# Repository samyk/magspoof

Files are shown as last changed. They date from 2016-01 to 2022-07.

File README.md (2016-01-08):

# [MagSpoof](http://samy.pl/magspoof/) - credit card/magstripe spoofer
* Allows you to store all of your credit cards and magstripes in one device
* Works on traditional magstripe readers **wirelessly** (no NFC/RFID required)
* Can **disable** Chip-and-PIN (code not included)
* Correctly **predicts** Amex credit card numbers + expirations from previous card number (code not included)
* Supports all three magnetic stripe tracks, and even supports Track 1+2 simultaneously
* Easy to build using Arduino or other common parts

**[MagSpoof](http://samy.pl/magspoof)** is a device that can spoof/emulate any magnetic stripe or credit card. It can work "wirelessly", even on **standard magstripe/credit card readers**, by generating a strong electromagnetic field that emulates a traditional magnetic stripe card.

**Note:** MagSpoof does **not** enable you to use credit cards that you are not legally authorized to use. The Chip-and-PIN and Amex information is **not** implemented and using MagSpoof requires you to have/own the magstripes that you wish to emulate. Simply having a credit card number and expiration is not enough to perform transactions. MagSpoof **does** allow you to perform research in other areas of magstripes, microcontrollers, and electromagnetism, as well as learn about and create your own devices similar to other existing, commercial technologies such as <a href="http://www.samsung.com/us/support/answer/ANS00043865/997410383/">Samsung MST</a> and <a href="https://onlycoin.com/">Coin</a>.</p>

Visualizing magstripe data (http://samy.pl/magspoof/meter-small2.gif)

MagSpoof can be used as a traditional credit card and simply store all of your credit cards (and with modification, can technically disable chip requirements) in various impressive and exciting form factors, or can be used for security research in any area that would traditionally require a magstripe, such as readers for credit cards, drivers licenses, hotel room keys, automated parking lot tickets, etc.

**Live demonstration** and more details available in the video:
<a href="https://www.youtube.com/watch?v=UHSFf0Lz1qc" target="_blank">MagSpoof</a>

**Point of Contact:** [@SamyKamkar](https://twitter.com/samykamkar) // <code@samy.pl> // <http://samy.pl>

**Released:** November 24, 2015

**Source code / schematic:** [https://github.com/samyk/magspoof](https://github.com/samyk/magspoof)

-----

# How magnetic stripes work

Visualizing magstripe data (http://samy.pl/magspoof/iron-oxide-short-low.gif)

Magnetic stripes (magstripes) are in fact magnetic. What's so cool about magstripes is that while the magnetic strips inside are weak, they're still strong enough to attract small ferrous particles and wide enough that we can **fully extract all data from a magstripe or credit card with the naked eye**. 

In the video, I actually dip my credit card into a bag of iron oxide. The magnetic elements in the magstripe attract the iron oxide and after pulling it out, you can actually see each bit in the tracks. [Financial cards](https://en.wikipedia.org/wiki/Magnetic_stripe_card#Financial_cards) with magnetic strips can have up to three tracks, however credit cards only have two tracks (Tracks 1 and 2). Track 2 stores fewer bits than Track 1, so it has a lower linear density (bits per inch).  This makes Track 2 much easier to see. Let's take a look:

Credit card magnetic stripe (http://samy.pl/magspoof/mag1.png)

Front of card:

Credit card magnetic stripe (http://samy.pl/magspoof/cc-front.jpg)

As you can see on my card, I've written out the bits above the strips. Two solid stripes is a 1 and a stripe followed by a space is a 0. First, let's flip the card 180 degrees (looking at it upside down), and read it as least significant bit first. We ignore all the initial 0's until the very first 1.

Track 2 is 5 bits per character, least significant bit first, and the 5th bit is an odd parity bit. By taking each 5 bits and reading the first 4 bits, we can now begin extracting the credit card number (and other data, such as expiration date, discretionary data, CVV/CVC/CSC/CID/CAV depending on card type).

Note that the CVV is different than the CVV2. The CVV is stored on the magstripe, while the CVV2 is printed on a card. (CVV is specific to Visa, and each issuer has their own name such as CSC, CVC, etc.)

Credit card magnetic stripe (http://samy.pl/magspoof/cciron.jpg)

------

# How MagSpoof Works

MagSpoof emulates a magnetic stripe by quickly changing the polarization of an electromagnet, producing a magnetic field similar to that of a normal magnetic stripe as if it's being swiped. What's incredible is that the magstripe reader requires no form of wireless receiver, NFC, or RFID -- MagSpoof works wirelessly, even with **standard magstripe readers.** The stronger the electromagnet, the further away you can use it (a few inches in its current iteration).

MagSpoof also uses inexpensive, off the shelf parts (described in the Hardware section), and can be built with almost nothing more than an Arduino, wire and a battery! I use a motor driver to provide a reasonable amount of power.

Normally electromagnets have an iron core, however we lose the core for the sake of space and portability. Also, while the iron core does make the electromagnet more efficient, we still produce more than enough power to work.

**MagSpoof improves on new cards such as Coin.** I'm a customer of Coin, and while I love their app and the card, the card actually works a very small percentage of the time. After looking over Coin's FCC docs, I noticed they use two coils to produce a (very small) electromagnetic field, however it's severely deficient and the card works less than 50% of the time for me, sadly.

I found that by emulating a card with MagSpoof, if I send Track 1 one way, and then send Track 2 reversed, every card reader will assume I simply swiped a card back and forth, use the data from both tracks and my strong electromagnet, and properly read all of the data. This is extremely effective, uses only a single coil, and works for both tracks simultaneously. This also allows MagSpoof to work on Track 3.

Additionally, if you're using a Chip card with Coin, you **still** need to bring your actual credit card to dip, however because MagSpoof can disable Chip-and-PIN (see below), it does **not** require you to bring your card with you.

I've removed the Chip-and-PIN disabling functionality from MagSpoof.

-----

# Security Issues

One of the primary issues I've found is that some of the new forms of security (well, new in the US) are set in the "service code" portion of the magstripe, most specifically **Chip-and-PIN.**

The service code within a credit card magstripe defines several attributes of the card, including whether the card can dispense cash, where it can work (nationally, internationally), and most interestingly, whether the card has a built in IC (Chip) and if it has a pin (Chip-and-PIN / EMV).

If your card has a chip inside and you go to a retailer that supports Chip but swipe just your magstripe, the point of sale (PoS) system will ask you to dip your card/chip for additional security if it supports it.

**However, the bits stating the card has Chip-and-PIN can be turned off from the magstripe.** This means if you take a card to a retailer that would normally request you to dip, you can actually get away with not dipping your chip at all while performing a successful transaction, **evading the security measures altogether**.

Credit Card Service Codes (http://samy.pl/magspoof/servicecodes.jpg)

------

# American Express Card Number Prediction

What initially led me to investigate magnetic stripes was my Amex card. After losing a card and Amex quickly sending me a replacement, I noticed many of the digits were similar. I pulled up the numbers to several other Amex cards I had, and then compared against more than 20 other Amex cards and replacements and found **a global pattern that allows me to accurately predict American Express card numbers by knowing a full card number, even if already reported lost or stolen.**

This means if I were to obtain your Amex card and you called it in as lost or stolen, the moment you get a new card, I know your new credit card number.

I also know the new expiration date as the expiration date is fixed based on when the new card was requested, and you can determine if the new card has been requested by performing an auth on the existing card.

The CID (aka CVV2 on Visa) printed on the card is protected by a secret 3DES key that encrypts the PAN (Primary Account Number, aka credit card number), service code (see above), and expiration. The service code can be easily determined as most cards will contain the same service code.

I also determined that the CSC (essentially behaves like a CID or CVV2 on the magstripe) for a lost or stolen card **continues to work** for a newer, predicted card. An attacker would be able to use a stolen card's CSC with the predicted card number and expiration to make actual purchases.

To actually perform the transaction without arousing suspicion, an attacker would be able to use a magstripe writer (e.g., the well known MSR605), or a device like MagSpoof, to "load" the newly devised card information onto a card like Coin. Coin itself does not actually verify the CID (CVV2), thus allowing an attacker to load data, and then use the Coin card in person without knowing the CID and exploiting these various issues, as well as disabling Chip-and-PIN.

I notified American Express of the issue and I will not be releasing their algorithm.

-----

# Hardware

MagSpoof (http://samy.pl/magspoof/magspoof.jpg)

### [Atmel ATtiny85](http://amzn.to/1S3ha9s) (microcontroller)
An Atmel ATtiny85 is the microcontroller to drive the entire system. It stores all of the magnetic stripe / credit card data. In a thinner, credit-card sized (0.8mm thick!) version, I use an [ATtiny10].

### [L293D H-Bridge](http://amzn.to/1S3h9Ck) (motor driver)
I use an L293D H-bridge to drive the electromagnet. The L293D is a motor driver, but motors are actually driven by the electromagnet(s) and magnets inside of them. Any standard driver should work here. Technically the L293D doesn't work down at 3.7V (voltage of the LiPo battery), but it works surprisingly well. In the credit-card size version, I suggest using a the TI DRV8835 or [TI DRV8833](http://amzn.to/1lu0bTd).

### [24AWG Magnet Wire](http://amzn.to/1lu0ihK) (coil)
I use somewhere around ~24AWG magnet wire to act as the coil to produce the electromagnetic field. This piece of wire incredibly produces an electromagnetic field that makes the card reader believe a card is being swiped. Incredible. By rapidly controlling the polarization of this field, the magstripe reader believes the flipped bits of a real card are being swiped through the reader.

### [100mAh 3.7V LiPo battery](http://amzn.to/1S3h69E) (the powah)
A small 100mAh 3.7V lipo battery powers our contraption. For the credit card size version (not shown here), I use a battery from [PowerStream](http://www.powerstream.com/thin-lithium-ion.htm).

#### [100µF Capacitor](http://amzn.to/1MAONOc)
Keep enough energy in this capacitor to provide the electromagnet with power when we need it, otherwise it will pull too much current and reset the microcontroller. This is the capacitor kit I use as it has all the standard values I'd need.

#### [LED](http://amzn.to/1Hl3y8Z)
To signal to us when we transmit information. I use this LED kit as it has a nice variety of LEDs.

#### [100Ω Resistor](http://amzn.to/1IeCMtP)
Don't burn out the LED.

#### [Momentary Switch](http://amzn.to/1Hl3R3T)
Initiate the electromagnet.

#### [Mini-Protoboard](http://amzn.to/1Hl3VQV)
For soldering everything together.

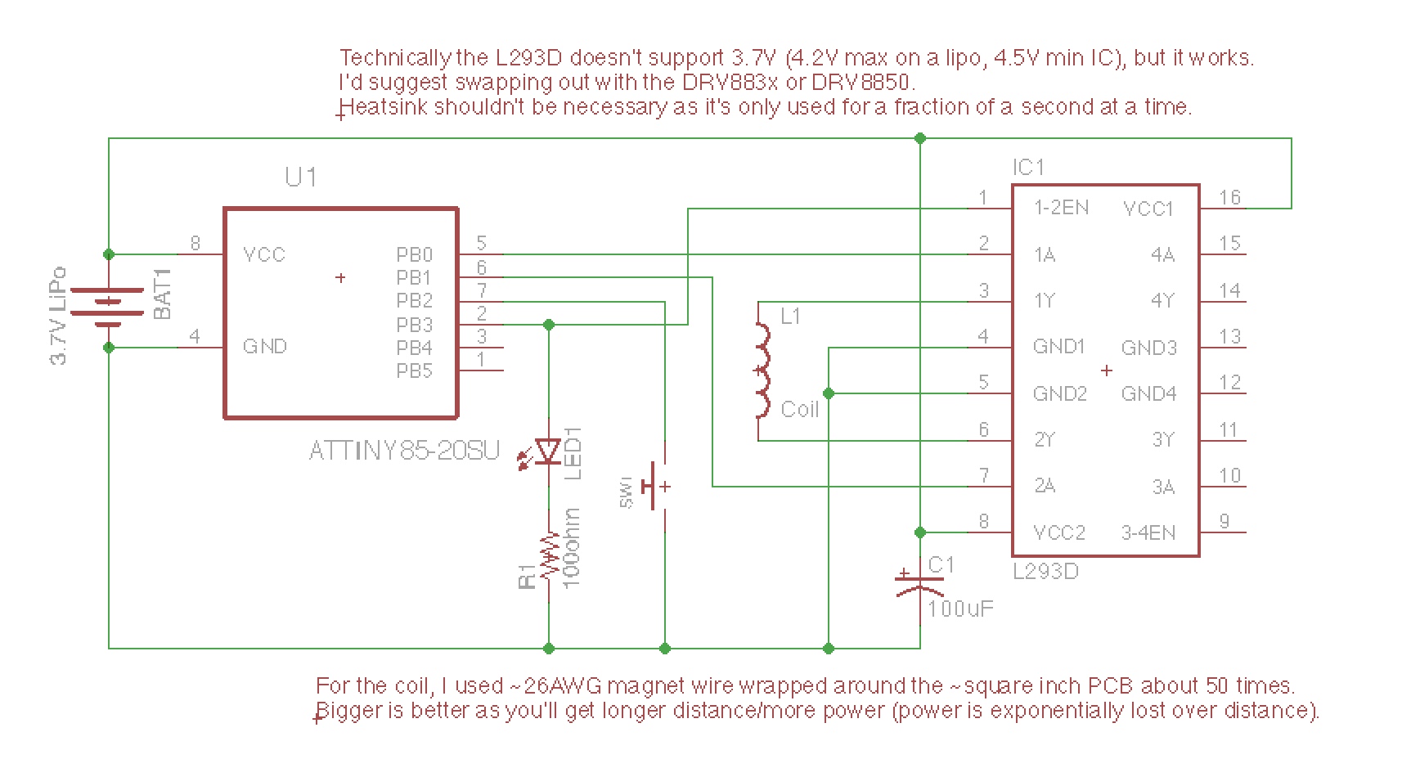
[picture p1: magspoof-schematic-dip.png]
MagSpoof Schematic (DIP version)


-----

# Firmware

### MagSpoof
MagSpoof's source code and schematic can be obtained in entirety from my github: <https://github.com/samyk/magspoof>

MagSpoof is compatible with the Arduino framework and can work on traditional Arduinos as well as ATtiny chips.

-----
# Resources

You can learn about magnetic stripes and credit cards from a few places, including:

* [My video on MagSpoof](https://www.youtube.com/watch?v=UHSFf0Lz1qc)
* [ISO/IEC 7810](https://en.wikipedia.org/wiki/ISO/IEC_7810)
* [ISO/IEC 7811](https://en.wikipedia.org/wiki/ISO/IEC_7811)
* [ISO/IEC 7812](https://en.wikipedia.org/wiki/ISO/IEC_7812)
* [ISO/IEC 7813](https://en.wikipedia.org/wiki/ISO/IEC_7813)
* [ISO 8583](https://en.wikipedia.org/wiki/ISO_8583)
* [ISO/IEC 4909](https://en.wikipedia.org/wiki/ISO/IEC_4909)
* [MagTek Magnetic Stripe Standards](http://www.magtek.com/documentation/public/99800004-1.08.pdf) (pdf)
* [Magnetic Stripe Card on Wikipedia](https://en.wikipedia.org/wiki/Magnetic_stripe_card)
* [Amex's Web Services Plural Interface](http://secure.cmax.americanexpress.com/Internet/MSWS/English/PIP-XML_Oct2010.pdf)

-----

# Contact

**Point of Contact:** [@SamyKamkar](https://twitter.com/samykamkar)

You can see more of my projects at <http://samy.pl> or contact me at <code@samy.pl>.

------

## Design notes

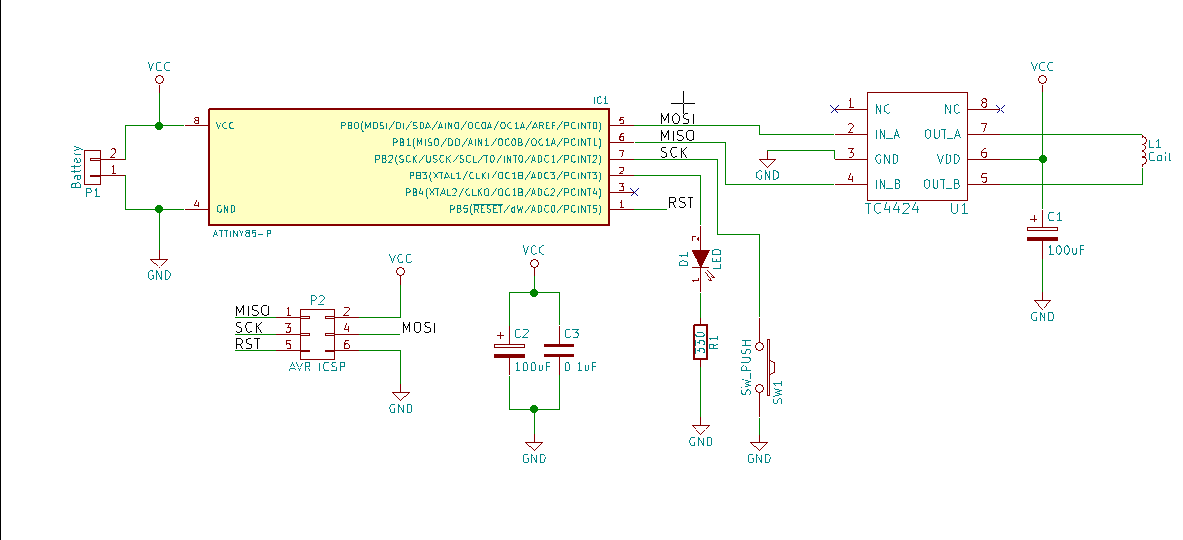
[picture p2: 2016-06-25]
KiCad-PCB/Schematic.png

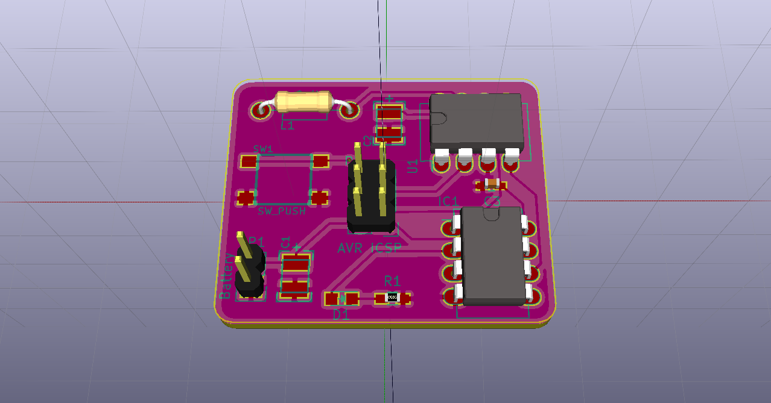
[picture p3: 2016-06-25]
KiCad-PCB/RenderBoard.png

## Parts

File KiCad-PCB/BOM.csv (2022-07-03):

Reference, Value, Footprint, Datasheet, Manufacturer, Temperature, Feed, Description, Temperatura, Alimentacion, Descripción
IC1,ATTINY85-P,Housings_DIP:DIP-8_W7.62mm_LongPads,http://www.farnell.com/datasheets/1744708.pdf,ATMEL,+85*C/-40*C,5v,Low Power High Performance ATMEL ATTINY85-20PU Microcontroller 20MHZ 8 Bits 8 KB 512 Byte 8 Pin Dip Through hole, +85*C/-40*C,5V, Baja Potencia Alto Rendimiento ATtiny Microcontrolador 20 MHz 8 KB 512 Byte 8 pines zambullida través agujero
D1,LED,LEDs:LED-0805,,Maxim,+85/-40,5v,Led red 0805
L1,Coil,Resistors_ThroughHole:Resistor_Horizontal_RM10mm,
R1,330,Resistors_SMD:R_0603_HandSoldering,,,+85/-40,5v,Resistor 330ohms
C1,100uF,theinventorhouse:1411(3528m)-B%2CM%2CH%2CT-TANTALUM,http://www.farnell.com/datasheets/1923743.pdf,Kemet,+85/-40,6.3v,KEMET 	T520T107M006ATE070  CAP, TANT, POLYMER, 100UF, 6.3V, 1411
SW1,SW_PUSH,open-project:SW_PUSH_SMD,
P2,AVR ICSP,Pin_Headers:Pin_Header_Straight_2x03,,Maxim,+85/-40,5v,
P1,Battery,Pin_Headers:Pin_Header_Straight_1x02,
C3,0.1uF,Capacitors_SMD:C_0603_HandSoldering,http://www.farnell.com/datasheets/2009679.pdf,WALSIN,+85/-40,50v,WALSIN 	0603F104Z500CT  CAP, MLCC, Y5V, 0.1UF, 50V, 0603, REEL
U1,TC4424,Housings_DIP:DIP-8_W7.62mm_LongPads,http://www.farnell.com/datasheets/95980.pdf,Microchip,+85/-40,2.7-5v,MICROCHIP 	TC4424CPA  MOSFET Driver Lado Bajo, Alimentación:4.5-18V, Salida Pico:3A, Salida:3.5 Ohm, DIP-
C2,100uF,theinventorhouse:1411(3528m)-B%2CM%2CH%2CT-TANTALUM,http://www.farnell.com/datasheets/1923743.pdf,Kemet,+85/-40,6.3v,KEMET 	T520T107M006ATE070  CAP, TANT, POLYMER, 100UF, 6.3V, 1411

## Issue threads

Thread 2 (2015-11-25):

Having a license?

ifraixedes, 2015-11-25:
Hi @samyk

Nice job!

I would appreciate if you can define a license for all of this information; whatever you want, but it would be useful to know which one that leaving it under people and laws interpretations.

Thanks so much to release this information.

madmod, 2015-11-25:
+1 This is an awesome project and I would like to know if I can make my own version of this for friends. Also I'm investigating an iPhone case version powered by the camera flash led.

samyk, 2015-11-27:
I'll start reading up on licenses.

Great idea on one powered by the camera flash LED, that would be very cool. Please share any info if you do create that!

ifraixedes, 2015-11-27:
@samyk thanks for your time to think about it

Luabee, 2016-10-07:
Have you considered a license for this yet? I'm interested in building upon this project and selling it.

samyk, 2016-10-08:
I've created and added a license, and will likely use this for future projects and all previous projects which are not yet licensed.

License added to git and provided at https://github.com/samyk/bpl/

0ki, 2017-09-06:
Is that a joke?

Closed 2016-10-08.

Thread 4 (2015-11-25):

Pictures of credit card sized version

madmod, 2015-11-25:
Please consider adding this as it sounds really awesome and I'm sure everyone would love to see it!

0ki, 2015-11-26:
Do you mean the coin? Internet is full of pictures. Also, here's a promo video: https://www.youtube.com/watch?v=gJBZMUuhUrw

madmod, 2015-11-26:
No I already own a coin. It's pretty cool although I haven't gotten the NFC feature to work yet.

There are mentions of parts for a smaller credit card sized version of MagSpoof in the readme and it sounded like @sammyk already built one, however it is not in the video or pictures. I just bought the parts for the larger version showed on the protoboard and plan on making the smaller version on a PCB once I have a prototype working.

samyk, 2015-11-27:
I will put up a schematic and pics when I have a nicer version. Currently the difficult part is keeping the entire thing as thin as a traditional credit card (0.76mm). I'm trying various techniques of PCB etching but simply on thin copper layers, not on FR-4, and very small traces for the micro-sized UDFN and WQFN/WSON packaging.

Currently doing this all at home but open to suggestions/techniques or companies who can run small batches!

lovelaced, 2016-08-17:
Did this ever come to fruition? I'd love to see it.

Joshfindit, 2016-08-18:
In terms of getting it thin enough, how close is the tech that large companies use?
(Apple's lightning-cable video compression board comes to mind)

samyk, 2016-08-18:
Coin is a good example. Their card is just as thin as a normal card and sports BLE, NFC, magstripe and lipo.

loa, 2016-08-19:
Would be nice to get a open source/hardware version rolling. Hate my wallet and that I always have the wrong cards with me.

deltamelta, 2016-09-15:
send me ic's programmed i make you a thin prototypes card size or whatever size u want

samyk, 2016-10-08:
@deltamelta, really? Do you produce thin PCBs?

deltamelta, 2016-10-08:
well yeah contact me at frontbackuser at tuta .io

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

Graydog, 2016-12-01:
@samyk Maybe use copper wires that are connected in the same alignment as the mag stripes of a regular card, and find a different but small driver that can individually pulse an EM signal to a specific  thread, such that it emulates an actual magstrip whilst keeping the form factor of a credit card?

jLynx, 2018-08-02:
Any updates? This sounds interesting

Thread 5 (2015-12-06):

Magspoof sounds different than a card

madmod, 2015-12-06:
I've constructed magspoof according to the schematic here with all the same parts as the video, except that it is on a breadboard and running at 5v. (I also tried 3.3v with the same results.) I acquired information from one of my cards with the Android app [Rhombus](https://github.com/sshipman/RhombusLib) and was able to place a zip tie in the Coin reader to get both tracks off my card. After programming my microcontroller with the card data I am unable to get it to function with the coin app or Rhombus which also accepts some partial data. After listening to the audio output of the coin in regular usage (swiping my card) and while held near my magspoof coil the difference in sound is apparent. The real card has a much softer quality and sounds a lot like sliding a card along a surface. In contrast holding the reader above my coil has greatly varying results depending on the position and orientation of the reader. If I hold the coin reader centered above the coil there is a relatively faint signal, while holding the center over the extreme edge of the coil produces a signal several times greater. Both have a harsh "digital" sound which is very unlike the normal card swipe. Also I believe the signal from magspoof was longer than the card swipe, but that may be only related to how quickly I moved the card. Hopefully I will be able to gain access to an oscilloscope for further testing in two weeks or so, but in the meantime I was wondering if anyone had any suggestions for how I might troubleshoot this further.

samyk, 2015-12-06:
Yes, they will sound different but that is pretty irrelevant. A signal on a scope will help but I'd be more curious if your track data makes sense. If you can provide track data similar to yours with some numbers replaced with "9"s, then I can take a look to at least see if they're reasonable.

Closed 2015-12-06.

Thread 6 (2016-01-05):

Schematic or Code error on LED pin

shellster, 2016-01-05:
Hi,

The schematic shows that the LED is hooked to physical pin 3 of the ATtiny85, however, the code intializes ENABLE_PIN (which is the LED) to PB3.  According to my testing, and the ATtiny85 testing sheet, PB3 is on physical pin 2.  So either the code is wrong or the schematic.

Not a big deal, but it would be nice to have it corrected.

samyk, 2016-01-05:
Oops, thanks @shellster! Fixed in https://github.com/samyk/magspoof/commit/f7f1d3c868b5509da58ddc3946a1869d8c942584

Closed 2016-01-05.

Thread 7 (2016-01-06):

Consider L9110H

shellster, 2016-01-06:
Hi,

I've successfully built a magspoof, but I substituted the L9110H H-Bridge drivr 8 pin DIP package for your L293D H-Bridge driver.  My choice seems to work just fine, and seems to be a much better fit as it is considerably smaller, designed to function on 3.3v inputs, and contains exactly the number of pins needed for the magspoof.  I'm submitting it as a suggestion.  Here's the datasheet: http://www.elecrow.com/download/datasheet-l9110.pdf

samyk, 2016-01-06:
Great! Do you have Eagle? I'd accept a pull request with an alternate schematic using it

shellster, 2016-01-06:
I don't, and I've never learned how to do Eagle CAD.  I may submit a pull when I have time to learn it.

The schematic changes are straight forward for those who are interested:
1) There is no enable pin, so you simply remove the connection from the ATTINY85 on Pin 3 to the H-Bridge Driver.
2) The coil is attached to the H-Bridge on pins 1 and 4
3) Pins 5 and 8 are tied to GND
4) Pins 2 and 3 are tied to the C1 CAP/VCC line.
5) Pin 6 on the H-Bridge is tied to Pin 5 on the ATTINY85
6) Pin 7 on the H-Bridge is tied to Pin 6 on the ATTINY85

sabas1080, 2016-01-27:
#10

daijizai, 2016-05-12:
@sabas1080 thanks for sharing the kicad files. I'm trying to source components to build it, but I'm a complete noob to SMD components, PCB fabrication, and finding the right item. Case in point - I accidentally bought a 0.4 mm ceramic capacitor for the 0.1uF capacitor. Is there a BOM? I've been digging through sites trying to figure out how to determine exactly what I need to no avail. Any advice you can share to help me determine what I need?

sabas1080, 2016-05-13:
@daijizai for the 0.1uF
http://mexico.newark.com/walsin/0805b104m500ct/cap-mlcc-x7r-0-1uf-50v-0805-reel/dp/78Y5293

seach as "0.1uF 0805"

I'm working in the new version with more accessible components

sabas1080, 2016-06-25:
@daijizai I've new pull request with BOM and new version of PCB #11

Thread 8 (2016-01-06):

Question about track start sentinels

shellster, 2016-01-06:
Hi,

Sorry if this isn't the appropriate place to ask questions.  As I mentioned in a previous issue, I have successfully created a magspoof.  I used a USB card reader to grab the tracks off of one of my cards.  The Track 1 data begins with the usual '%' sentinel and Track 2 with a ';'.  The track information was added to the magspoof code and uploaded to an Attiny85.  However, when I attempt to use the magspoof on my card reader, everything comes back correctly, except the sentinels for both tracks.  In both cases, they are replaced with a '+' symbol.  Is this intentional?  I'm wondering if I have some sort of timing glitch on the first characters.  I have also, thus far, been unable to read both tracks simultaneously with the card reader, using magspoof.  I am still digesting the code, and it is possible that these are separate issues, but I was wondering if you might have some helpful input.

samyk, 2016-01-06:
I haven't run into anything like that -- in fact, I've never ran into an issue where any of the data was corrupt. The only issue I've ever experienced was the card not being read at all, at which point a second replay typically solves it.

Are you sure the software you're using isn't replacing the characters?

shellster, 2016-01-06:
Pretty sure it isn't the card reader, as it is the same reader that I used to record the tracks originally, which worked fine and correctly.  My magspoof is in prototype stage, so I can probably attribute it to a buggy connection or maybe noise.  It is consistently the first character on the track, and nothing else.  I'm going to play with it some more.  I just wanted to validate that it wasn't by design (I couldn't see how from the code).  It would probably work as the sentinel field isn't necessarily required to be the most common character, but now I know it is on my end.

samyk, 2016-01-06:
Weird. Only thing I'd suggest is playing with the number of leading zeros from 25 to a larger number (like 125), along with the BETWEEN_ZEROS to something larger as well. Would love to hear if you solve it and how, though I haven't heard of this before.

shellster, 2016-01-06:
So after jiggling my coil around, I'm getting occasional correct sentinels.  My coil isn't very big and so I currently have it jammed in the reader.  It has to be exactly positioned.  My current hypothesis is that the signal is very weak and when the card reader detects a "card" it is ramping up detection, which has the effect of it misreading the original character.  Why it is so consistent, I don't know.  Maybe '+' is code for "unable to read character correctly".  I'm going to wrap a nice large coil and properly soldier it to my leads, that will hopefully fix the issue permanently.  I'll report back once I've had a chance to do that.  I may need to consider a separate power source for the coil.  Right now, I'm running it from my teensy 3.1 which is also what I'm using to program the Attiny85.  When the coil is running the LED on my teensy gets very dim, which tells me that even with the cap, it's struggling with the load.

samyk, 2016-01-06:
Are you using a capacitor shown as in the schematic?

samyk, 2016-01-06:
Sorry, I see you mentioned cap -- how big? Try a bigger one :)

kevinaizic, 2018-05-09:
Bit late to the party, but I had this exact issue trying to spoof my student ID which is just track 2. No matter what I tried the first semicolon always became a plus sign or a plus sign would appear in front of the track when I omitted the start sentinel altogether (even when I tried it on track 1 with "%" which made it weirder). Using the MSR90 config tool I figured out "+" is its default prefix for track 3 and by default it doesn't show the start sentinel (but it's "supposed" to be the same as the prefix which is why it doesn't usually matter), so seems like something caused it to think it's reading track 3, somehow.                  
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

I actually just got it fixed after hours of fiddling when I found this page, by both arbitrarily increasing the zeros as recommended (not sure if that helped), plus I realized moving the coil around to a different position finally gave a track 1 error suggesting it might have to do with the coil's position since I didn't change anything else, and finally flipping the reader so the coil faced the opposite side bestowed upon me that forlorn semicolon. I don't know how common this issue really is but hopefully there's an answer for the next person.

I'm also just working on a prototype but using a large coil I wound over an iron rod (less than 0.5A  at 3.7V since there are so many turns), plus a jellybean L298N board with pretty beefy built-in caps and high drain LiPo battery, so I feel like it's not  power delivery issue for something so specific and reproducible. My magspoof now works over an inch or so away though, which I'm proud of. Next step is building my own obscenely high current H-bridge and using quite a bit more voltage for the coil to see how much range it can realistically get before qualifying as an EMP... Anyway I can't stress enough that I have no idea what I'm doing, but if I had to guess this issue is likely a flaw in the design of these MSR card readers, or maybe some quirk in the nature of blasting them with radiation from afar instead of their intended use...

Closed 2016-01-06.

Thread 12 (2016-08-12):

Missing Line from magspoof.c

amustafa, 2016-08-12:
Line 31 of magspoof.c starts of with a string and line 33 ends with an closing semicolon that doesn't pair with anything.

Looking into the file history, it appears that the first line in this statement got deleted:

    const char* tracks[] = {
    "%B123456781234567^LASTNAME/FIRST^YYMMSSSDDDDDDDDDDDDDDDDDDDDDDDDD?\0", // Track 1
    ";123456781234567=YYMMSSSDDDDDDDDDDDDDD?\0" // Track 2
     };

bugduino, 2016-08-27:
+1

Closed 2016-08-27.

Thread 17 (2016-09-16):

Powered by CR2032?

aph3rson, 2016-09-16:
It seems as if all of the elements of the circuit (using the alternate motor driver, DRV8835) can run on 3V, and the button-cell has a significantly-higher mAh rating. Is there anything preventing the usage of a coin-cell battery to power this device? Would the field be so small, it'd be practically-unusable?

exploitagency, 2017-04-02:
The RyscCorp v2 version of this uses a CR2032 and a PCB Antenna Coil.
Wireless spoofing seems limited so far.
https://legacysecuritygroup.com/index.php/projects/recent/10-magnetic-stripe/40-rysc-corp-magspoof-v2-first-look

Dehyrf, 2017-07-11:
I put together a low-cost v2 spin of my own, adding a DRV8835, USB for power and on-the-fly reprogramming, and a cr2032 power source: https://circuitmaker.com/Projects/Details/Q-B/MagSpoofv2

Dehyrf, 2017-07-11:
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

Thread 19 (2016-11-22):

It's sending the same track 3 times in a row

mtagius, 2016-11-22:
I reproduced the circuit on a breadboard and I uploaded the code provided.  I am testing it with a Magtek card reader and when I try to have magspoof send a track of data my card reader says it is sending the data 3 times in a row.  I had the arduino print the data being sent over serial and it seems to only be sending the data once.  Am I making a mistake somewhere?

Thank you

mtagius, 2016-12-01:
I find I am getting different results with different models of Magtek readers.  I believe that was the cause of my problem.

samyk, 2016-12-01:
Strange. You might want to try changing the timing by increasing or decreasing the delays in the code, as you're essentially emulating a human "swiping" the card.

cheeseandcereal, 2017-04-30:
I've been playing around with a few different card readers, and I believe this issue occurs depending on the implementation of the magstripe reader itself. The difference between magspoof and a physical card is that with a physical card, any particular track can ONLY be read from a single physical location on the read head in the magstripe reader. Magspoof has no physical discretion, and blasts out the magnetic information to whatever is close enough to read it. This means that a single track sent by magspoof can be read multiple times (as different tracks) by a magstripe reader, depending on the implementation of the magstripe reader itself.

There is some great information on magstripe readers here that may help to explain some of this: https://github.com/carlosefr/magstripelib

This is the main problem preventing 100% compatibility between magspoof and every single card reader.

mtagius, 2017-04-30:
That makes a lot of sense.  I think that is the solution.  Would that explain why my USB reader gets the data 3 times but the vending machine I tested this on had no problems and charged my card?  Did it work because the vending machine reader probably can only read one track at a time?  Can magspoof ever work with readers that simultaneously read more than one track?  Thank you

cheeseandcereal, 2017-04-30:
Yes, that would almost certainly be why your USB reader is reading the data 3 times. I know of one magtek reader that alternates the single read head for all 3 tracks, to be able to read all tracks simultaneously. Although I don't have one myself, I imagine the read head is reading each byte sent by magspoof 3 consecutive times, at a different physical location, thinking they are 3 separate tracks since it's reading the same data in 3 different physical locations.

I've found most standard credit card readers will be able to parse magspoof regardless, since they will often accept your card even if it can only correctly read and verify one track. So often, even in worst case scenario, if the card reader is reading a single track from magspoof 3 times, it will simply ignore the 2 invalid tracks and accept the valid one.

I believe most, card readers nowadays have the ability to read multiple tracks simultaneously. The differentiation really comes down to the software implementation and how it chooses to parse/verify/ignore the data read off of the magstripe reader itself.

So while the data read off of a card reader might not look exactly the same as a card swipe which can present multiple tracks at once, the software interpreting and dealing with the data off of the magstripe reader can be written so that it is always correctly interpreted. This is usually the case with regular credit card readers at POS, vending machines, etc, since they generally treat separate tracks as backup redundancy rather than requiring the data to always come in perfectly.

So to answer your question, to get the data to look exactly like a credit card for all readers is simply not possible, although something closer may be possible with multiple coils emulating different tracks simultaneously.

mtagius, 2017-04-30:
Wow, that clears up a lot for me.  I thought I was sending the data wrong.  I really appreciate such a detailed response.  Thank you.

samyk, 2017-04-30:
Do note that I played with the timing and replaying methods quite a bit to find something that worked across the most number of magstripe readers despite having only a single coil. Also note that magspoof works quite a lot better than the multicoil Coin card, likely due to the strong EM force generated. I'm open to changes but you will want to perform significant testing if you do adjust things.

cheeseandcereal, 2017-04-30:
Well like I said, the issue really isn't with the hardware/software implementation of magspoof, but rather the 'issue' is simply the idea of using a powerful EM force to send the data, since that EM force has no physical discretion.

In most cases, the magstripe readers are able to differentiate tracks with the start sentinels, however other implementations of a readers act differently. I've even come across readers that will completey ignore and/or replace the start sentinel read off the card with whatever the reader thinks should be there, based on the physical location where the read head gets the data. With readers like that, there simply is nothing that can be done.

I can definitely see how a multi-coil solution could work even worse with confounding EM fields. I haven't actually tried that, so my suggestion of multiple coils was more of an untested theoretical.

samyk, 2017-04-30:
I understand, however I'm noting that my implementation was by design to work across the greatest number of PoS credit card readers as possible (and NOT intended for 3-track readers). I found that 2-track readers will often read both tracks from magspoof properly as if the user is swiping their card back and forth, where the first swipe it only reads one track properly and fails on the 2nd, but on the "swipe back" it reads the 2nd track properly while keeping the 1st in memory. I described this in the writeup and is the reason magspoof performs the reverse track playing.

As I did do significant testing with Coin (two coils in the correct track locations) I found failure rates near 50% on traditional PoS readers, while magspoof works nearly 100% with the reverse-track playing technique.

Closed 2016-12-01.

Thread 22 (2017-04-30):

Plays Track1+2, then ONLY Track 2 every other "press"

cheeseandcereal, 2017-04-30:
With the current implementation of the code, the first time you press the button, it will call playTrack(1), then next time you press the button, it will call playTrack(2) (because of how it keeps track and increments curTrack)

This doesn't make a lot of sense, because when calling playTrack(1), it will actually play BOTH tracks because of this if statement within the method:
`  // if track 1, play 2nd track in reverse (like swiping back?)
  if (track == 0)
  {
    // if track 1, also play track 2 in reverse
    // zeros in between
    for (int i = 0; i < BETWEEN_ZERO; i++)
      playBit(0);

    // send second track in reverse
    reverseTrack(2);
  }`

Then after playing both tracks, next time you press the button it will call playTrack(2) which will ONLY play the 2nd track because that if statement isn't satisfied.

Essentially this means that every other time you press the button, the magspoof will ONLY play track 2. All other times it will play both tracks.

This doesn't make a lot of sense, and it should probably be changed by either:

1. Getting rid of curTrack entirely, and simply replace the line
`playTrack(1 + (curTrack++ % 2));` with `playTrack(1)`

OR

2. Remove the reverse track implementation entirely, then simply call playTrack(1) and playTrack(2) sequentially.

zooyn, 2019-08-15:
Im having the same issue except that my goal is to display both tracks 1+2 consistently after every press of the button. Does anybody know how what configurations I should do with the source code?

I think it has something to do with this part of the code:

void loop()
{

  //for(int i=0;i<10;i++){playTrack(1+(curTrack++%2));delay(3000);}

  sleep();

  noInterrupts();
  while (digitalRead(BUTTON_PIN) == LOW);
  playTrack(1 + (curTrack++ % 2));
  delay(50);
  while (digitalRead(BUTTON_PIN) == LOW);
  playTrack(1 + (curTrack++ % 2));
  delay(400);

  interrupts();
  //playTrack(1 + (curTrack++ % 2));
}

Any help will be much appreciated

Immrspy, 2020-02-03:
Samy has stated that this is WAI in #31 , If you want to just run both at the same time, set the main loop to say "playTrack(1);", then it will do the run 1 forward and 2 backwards scheme.

roboyaar, 2023-01-10:
> Samy has stated that this is WAI in #31 , If you want to just run both at the same time, set the main loop to say "playTrack(1);", then it will do the run 1 forward and 2 backwards scheme.

how should i change the code for cards which have only second line on them?
would you pls help me?

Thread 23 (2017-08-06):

[Not an issue] 1$ ATTINY85 Programmmer

BlueArduino20, 2017-08-06:
I've found a 1$ programmer for the ATTINY85 to upload the code more easily:
https://aliexpress.com/store/product/DIYmall-Development-Programmer-Board-With-Pins-for-ATtiny13A-ATtiny25-ATtiny45-ATtiny85-ATTINY85-20PU-DIP-8-ATMEL/406986_3278215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

Closed 2018-01-01.

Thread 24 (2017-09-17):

CR2032 and no motor driver?

Leseratte10, 2017-09-17:
I'd like to replicate this build / project but I have a few questions (so this is not really an "issue"):

First, I have found this web page http://www.idogendel.com/en/archives/507 which states that the motor driver is not really needed, because you don't necessarily have to switch the polarity of the magnetic field, turning it on and off with a transistor would be enough. Is that actually true?

Second, what about powering the circuit with a CR2032 cell? (I am aware of #17 ) The current project doesn't seem to have any discharge protection to protect the Lipo cell from over-discharge, does it?

A typical CR2032 has >200mAh, and the ATtiny needs almost nothing (0.3 µA = 0.0003 mA is what I've read, so, a battery standby time of basically infinity.

Can I just replace the Lipo battery cell with a CR2032 or does that not provide enough power for the coil? Does anyone happent to have schematics for that mod? Should / Do I need to increase the capacity of C1?

samyk, 2017-09-17:
1. It's true, just like bypass caps aren't always needed. It might work in some cases, and in others, it won't work. Drive it properly and you will increase the readers it will work on (it's worked on all readers that I've tested). Additionally, you'll be limited by the source current of the pins, drastically limiting your output and reducing your range significantly. Thus, use a driver if you want some real current output.

2. Sure, CR2032 should be fine. The cap is necessary to charge up to provide sufficient power when activating (and it may not recharge as quickly with a CR2032, but shouldn't be a big deal). Don't forget the power used by the electromagnet in your calculations. Same size should be fine, let us know how it goes!

Closed 2017-09-17.

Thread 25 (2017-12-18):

issue playing track 2+3 without track 1

herrmanns, 2017-12-18:
hello, i am new to this and would like to understand what i am doing wrong. i just want to use track 2 and 3. the start sentinel of each are ";"
btw i am using the original magspoof.c of samyk.
// consts get stored in flash as we don't adjust them
const char* tracks[] = {
";672xxxxxxxxxxxxxxxxx=xxxxxxxxxxxxxxxxxx?\0", // Track 2
";01xxxxxxxxxx=xxxxxxxxxxxxxxx=xxxxxxxxxxxxxxxxxxxxxxxxxxxxxxxxxxxxxxxxxx==x=xxxxxxxxxxxxxxxx?\0", // Track 3
};

it will only use the 2nd row beginning with ";01 blabla when i press the button. row 1 is ignored.
when i use "%672 blabla it works without any issues. but "%" is the start sentinel of track 1 which i dont need.

how do i have to change code to accept track 2 and track 3 only?

thank you and best reagrds

samyk, 2017-12-18:
MagSpoof is still attempting to play those as track 1 & 2 which won't work as track 1's bits per character is different than track's 2 & 3. You need to make sure tracks[] contains **three** values (first one can be empty), then make sure in the loop change `playTrack(1` to `playTrack(2`

herrmanns, 2017-12-18:
Thank You! I 'm sorry but I have no programming skills :)
It does the trick. Chaepeau!

Closed 2018-12-03.

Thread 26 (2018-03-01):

Adding more than one card

martianman1999, 2018-03-01:
I am not very familiar programing in C I have tried to add the ability to hold and use more than one card if you could offer some guidance that would be great. I have the full code on the Arduino Community forums.
https://forum.arduino.cc/index.php?topic=532381.0
Thank you very much

fantuz, 2018-03-01:
Hi, you did an interesting thing. Porting something to Arduino. I did the same with my software, DNSPRoxy.

The quality of your code seems pretty high, you implement all the best practices to avoid delays and minimise number of calls or iterations of the such (all the shifts and beauty).

I have to point out 3 things:
- you post the code but not stating"which" is the problem
- you open a thread on another forum, that needs login
- you could fork the project, do the (very clever) modifications and discussions on your branch, then create a pull request to the owner.

Sorry, I will even try to help you as I love both Kami works and microcontrollers, i will try to compile in my arduino IDE to see if anything bad pops up, but you shall at least specify how the specific/unknown issue reproduces/manifests....

As weel, after forking you could add diagram of the hardware setup you are talking about.

Apologise me if I am OT/wrong.
Cheers and bravo @martianman1999 for porting

martianman1999, 2018-03-01:
Thank you very much for your reply I'm very new to programing and how to properly post of forums. My problem is that I am unsure what the proper name and avenue I should be taking I have a general idea on what the code should look like but the OG code is very complex and I am trying to preserve it's functionality.
Also sorry I didn't know you needed a login to see the post.

martianman1999, 2018-03-01:
The code I am using is:

/*
 * MagSpoof - "wireless" magnetic stripe/credit card emulator
*
 * by Samy Kamkar
 *
 * http://samy.pl/magspoof/
 *
 * - Allows you to store all of your credit cards and magstripes in one device
 * - Works on traditional magstripe readers wirelessly (no NFC/RFID required)
 * - Can disable Chip-and-PIN (code not included)
 * - Correctly predicts Amex credit card numbers + expirations from previous card number (code not included)
 * - Supports all three magnetic stripe tracks, and even supports Track 1+2 simultaneously
 * - Easy to build using Arduino or ATtiny
 *
 */
#include <avr/sleep.h>
#include <avr/interrupt.h>

#define PIN_A 0
#define PIN_B 1
#define ENABLE_PIN 3 // also green LED
#define SWAP_PIN 4 // unused
#define BUTTON_PIN 2 // Send Tracks
#define CLOCK_US 200
#define BETWEEN_ZERO 53 // 53 zeros between track1 & 2
#define TRACKS 2
/*New Varables*/

#define PINCARD1 8
#define PINCARD2 9
#define PINCARD3 10

// consts get stored in flash as we don't adjust them
const char* CARD1[] =
{
"%Card1^LASTNAME/FIRST^YYMMSSSDDDDDDDDDDDDDDDDDDDDDDDDD?\0", // Track 1
";123456781234567=YYMMSSSDDDDDDDDDDDDDD?\0" // Track 2
};

const char* CARD2[] =
{
"%Card2^LASTNAME/FIRST^YYMMSSSDDDDDDDDDDDDDDDDDDDDDDDDD?\0", // Track 1
";123456781234567=YYMMSSSDDDDDDDDDDDDDD?\0" // Track 2
};

const char* CARD3[] =
{
"%Card3^LASTNAME/FIRST^YYMMSSSDDDDDDDDDDDDDDDDDDDDDDDDD?\0", // Track 1
";123456781234567=YYMMSSSDDDDDDDDDDDDDD?\0" // Track 2
};

/*
const char* tracks[] =
{
"%B123456781234567^LASTNAME/FIRST^YYMMSSSDDDDDDDDDDDDDDDDDDDDDDDDD?\0", // Track 1
";123456781234567=YYMMSSSDDDDDDDDDDDDDD?\0" // Track 2
};
*/

char revTrack[41];

const int sublen[] = {
  32, 48, 48 };
const int bitlen[] = {
  7, 5, 5 };

unsigned int curTrack = 0;
int dir;

void setup()
{
  pinMode(PIN_A, OUTPUT);
  pinMode(PIN_B, OUTPUT);
  pinMode(ENABLE_PIN, OUTPUT);
  pinMode(BUTTON_PIN, INPUT_PULLUP);

  pinMode(PINCARD1, INPUT_PULLUP);
  pinMode(PINCARD2, INPUT_PULLUP);
  pinMode(PINCARD3, INPUT_PULLUP);

  // blink to show we started up
  blink(ENABLE_PIN, 200, 3);

  // store reverse track 2 to play later
  storeRevTrack(2);
}

void blink(int pin, int msdelay, int times)
{
  for (int i = 0; i < times; i++)
  {
    digitalWrite(pin, HIGH);
    delay(msdelay);
    digitalWrite(pin, LOW);
    delay(msdelay);
  }
}

// send a single bit out
void playBit(int sendBit)
{
  dir ^= 1;
  digitalWrite(PIN_A, dir);
  digitalWrite(PIN_B, !dir);
  delayMicroseconds(CLOCK_US);

  if (sendBit)
  {
    dir ^= 1;
    digitalWrite(PIN_A, dir);
    digitalWrite(PIN_B, !dir);
  }
  delayMicroseconds(CLOCK_US);

}

// when reversing
void reverseTrack(int track)
{
  int i = 0;
  track--; // index 0
  dir = 0;

  while (revTrack[i++] != '\0');
  i--;
  while (i--)
    for (int j = bitlen[track]-1; j >= 0; j--)
      playBit((revTrack[i] >> j) & 1);
}

// plays out a full track, calculating CRCs and LRC
void playTrack(int track)
{
  int tmp, crc, lrc = 0;
  track--; // index 0
  dir = 0;

  // enable H-bridge and LED
  digitalWrite(ENABLE_PIN, HIGH);

  // First put out a bunch of leading zeros.
  for (int i = 0; i < 25; i++)
    playBit(0);

  //
  for (int i = 0; tracks[track][i] != '\0'; i++)
  {
    crc = 1;
    tmp = tracks[track][i] - sublen[track];

    for (int j = 0; j < bitlen[track]-1; j++)
    {
      crc ^= tmp & 1;
      lrc ^= (tmp & 1) << j;
      playBit(tmp & 1);
      tmp >>= 1;
    }
    playBit(crc);
  }

  // finish calculating and send last "byte" (LRC)
  tmp = lrc;
  crc = 1;
  for (int j = 0; j < bitlen[track]-1; j++)
  {
    crc ^= tmp & 1;
    playBit(tmp & 1);
    tmp >>= 1;
  }
  playBit(crc);

  // if track 1, play 2nd track in reverse (like swiping back?)
  if (track == 0)
  {
    // if track 1, also play track 2 in reverse
    // zeros in between
    for (int i = 0; i < BETWEEN_ZERO; i++)
      playBit(0);

    // send second track in reverse
    reverseTrack(2);
  }

  // finish with 0's
  for (int i = 0; i < 5 * 5; i++)
    playBit(0);

  digitalWrite(PIN_A, LOW);
  digitalWrite(PIN_B, LOW);
  digitalWrite(ENABLE_PIN, LOW);

}

// stores track for reverse usage later
void storeRevTrack(int track)
{
  int i, tmp, crc, lrc = 0;
  track--; // index 0
  dir = 0;

  for (i = 0; tracks[track][i] != '\0'; i++)
  {
    crc = 1;
    tmp = tracks[track][i] - sublen[track];

    for (int j = 0; j < bitlen[track]-1; j++)
    {
      crc ^= tmp & 1;
      lrc ^= (tmp & 1) << j;
      tmp & 1 ?
        (revTrack[i] |= 1 << j) :
        (revTrack[i] &= ~(1 << j));
      tmp >>= 1;
    }
    crc ?
      (revTrack[i] |= 1 << 4) :
      (revTrack[i] &= ~(1 << 4));
  }

  // finish calculating and send last "byte" (LRC)
  tmp = lrc;
  crc = 1;
  for (int j = 0; j < bitlen[track]-1; j++)
  {
    crc ^= tmp & 1;
    tmp & 1 ?
      (revTrack[i] |= 1 << j) :
      (revTrack[i] &= ~(1 << j));
    tmp >>= 1;
  }
  crc ?
    (revTrack[i] |= 1 << 4) :
    (revTrack[i] &= ~(1 << 4));

  i++;
  revTrack[i] = '\0';
}

void sleep()
{
  GIMSK |= _BV(PCIE);                     // Enable Pin Change Interrupts
  PCMSK |= _BV(PCINT2);                   // Use PB3 as interrupt pin
  ADCSRA &= ~_BV(ADEN);                   // ADC off
  set_sleep_mode(SLEEP_MODE_PWR_DOWN);    // replaces above statement

  MCUCR &= ~_BV(ISC01);
  MCUCR &= ~_BV(ISC00);       // Interrupt on rising edge
  sleep_enable();                         // Sets the Sleep Enable bit in the MCUCR Register (SE BIT)
  sei();                                  // Enable interrupts
  sleep_cpu();                            // sleep

  cli();                                  // Disable interrupts
  PCMSK &= ~_BV(PCINT2);                  // Turn off PB3 as interrupt pin
  sleep_disable();                        // Clear SE bit
  ADCSRA |= _BV(ADEN);                    // ADC on

  sei();                                  // Enable interrupts
}

// XXX move playtrack in here?
ISR(PCINT0_vect) {
  /*  noInterrupts();
   while (digitalRead(BUTTON_PIN) == LOW);
   delay(50);
   while (digitalRead(BUTTON_PIN) == LOW);
   playTrack(1 + (curTrack++ % 2));
   delay(400);
   interrupts();*/

}

void loop()
{
#define tracks[]

  if (PINCARD1, LOW)
  {
    tracks[] = CARD1;
  }
  if (PINCARD2, LOW)
  {
    tracks [] = CARD2;
  }
  if (PINCARD3, LOW)
  {
    tracks[] = CARD3;
  }

  //for(int i=0;i<10;i++){playTrack(1+(curTrack++%2));delay(3000);}

  sleep();

  noInterrupts();
  while (digitalRead(BUTTON_PIN) == LOW);

  delay(50);
  while (digitalRead(BUTTON_PIN) == LOW);
  playTrack(1 + (curTrack++ % 2));
  delay(400);

  interrupts();
  //playTrack(1 + (curTrack++ % 2));
}

fantuz, 2018-03-01:
Sorry sorry i do not want to tear you down, just saying that this is not the right place to trow "generic" questions.

Probably in terms of questions about coding/implementation, arduino forum is still the right place to post and learn from, unless is a more logic/abstract thing that has interested in being shared between github and arduino forum itself. Anyway, you are linking two different communities, projects, mailing lists.... spamming the world :D if you are new, better to learn how to pose questions in a way that your effort will receive an answer, otherwise it will stay a mute thread (and be a loss of time to close the issue).

Even more you propose a "feature" so you should really fork, it might be easier for people to contribute more effectively (by pull request as said).
Look at the top-righ button at any repository frontpage, there will be a "FORK" button.

martianman1999, 2018-03-01:
Thank you very much

Closed 2018-03-01.

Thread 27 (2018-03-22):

Read error

blond1, 2018-03-22:
HI,
I have built my magspoof but it steel doesn't word: every time my readers ( i have 2) say read error
even if the information of the track is correct. I don't understand why. A wrong coil can do this sort of errors?
Thanks for your answer

andyjsmith, 2018-07-18:
Did you ever resolve your issue? I'm having the same problem, getting %E?;E?+E? on my card reader but normal cards work fine as well as using MST on my Galaxy S8.

blond1, 2018-07-18:
Hi
I finally bought a magspoof but i have the same error with mine and the other. Are you under Windows ?do you have telegram or whatapp ?

Télécharger Outlook pour Android<https://aka.ms/ghei36>

________________________________
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

andyjsmith, 2018-07-19:
Yeah, I'm on Windows 10. I have telegram.

If I understand you correctly, you have the same error on both your homemade magspoof and the one you bought (Rysc Corp?). Maybe it's an issue then with the card reader itself? I haven't had a chance to test mine out in the wild yet but maybe it works on normal commercial card readers?
Have you tried yours elsewhere?

blond1, 2018-07-19:
Give me your telegram

Télécharger Outlook pour Android<https://aka.ms/ghei36>

________________________________
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

samyk, 2018-12-03:
@andyjsmith Do you still have MST? Do you have an oscilloscope or logic analyzer where you could record how it looks? I believe MST came out slightly after MagSpoof and would love to see how it sends data.

blond1, 2018-12-03:
I have an Arduino. Can someone explain me the steps to follow?

Télécharger Outlook pour Android<https://aka.ms/ghei36>

________________________________
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

samyk, 2018-12-03:
You could use a coil of wire to connect to the ADC on the Arduino and sample data in. You'd probably want some diodes to protect the ADC pin though as I'm not sure how powerful the signal would be. Have any diodes? Also if you have something like a Teensy that would work even better.

andyjsmith, 2018-12-03:
I'm still having this issue but I can occasionally get it to work, but none of the readers I have tried have picked up multiple tracks, they either pick up the first track or the second, and no other data.

andyjsmith, 2018-12-03:
@samyk Didn't see your earlier reply, but yes I still have MST on my phone, unfortunately I do not have an oscilloscope but I could try a coil connected to an Arduino. You'd have to give me some advice about the diodes though, I have some that came in a kit but don't know which size/rating to use as I'm somewhat new to electronics.

blond1, 2018-12-03:
I will try next week because i will go to Jordan tomorrow.

Télécharger Outlook pour Android<https://aka.ms/ghei36>

________________________________
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

roboyaar, 2023-01-10:
how should i change the code for cards those have just second line on them?
would you pls help me?

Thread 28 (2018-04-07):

KiCAD Folder for the L293D Version

AJtheInventor, 2018-04-07:
Do you have a KiCAD PCB folder like the KiCAD PCB folder for the new version with TC4424, but for the old version with the L293D?

adukale, 2018-09-06:
Did you ever got KiCAD PCB folder with L293D?
If yes then can you share?
Thanks.

echow2001, 2021-03-03:
old post but I'm working on a fork using the qfn package components suggested and a more powerful microcontroller with simple LCD/keypad interface allow for on the fly load and create new save data. might look into BLE as well but got no idea where to start with some like that. something to replace MST eh

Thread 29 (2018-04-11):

Second LED Missing From Schematic

SynapticRewrite, 2018-04-11:
Maybe this is a dumb question, but the photos (protoboard) show two LEDs but the diagram only has one? (Also, photos of the backside of the board would be *awesome*). I'm just trying to recreate it for fun.

samyk, 2018-04-12:
I only used one ultimately. I had big plans for that second LED but ultimately simplified it. Just follow the schematic as it's much easier than the backside of the board.

Closed 2018-04-12.

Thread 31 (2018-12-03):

Emulation issues using DIY MagSpoof

jLynx, 2018-12-03:
Hi All

So I have just built my first magspoof and seem to be have a few issues.

I brought a magnetic card reader to dump my card details. When I swipe my card with the reader I get:
`%B4548605864141234^JAMES SMITH              ^2107205100000000000000208000000?;4548605864141234=21072051000000000208?`
_(I have altered the data, THIS IS NOT MY ACTUAL CARD DATA)_

Now when I use my MagSpoof I have just created I get this:
Push button once:
`%B4548605864141234^JAMES SMITH              ^2107205100000000000000208000000?;E?+B4548605864141234^JAMES SMITH              ^2107205100000000000000208000000?`
Push button again (2nd time)
`%E?;4548601577143445=21072051000000000208?+4548601577143445=21072051000000000208?`

I would assume I just need to press the button once for it to print out just like it did when I originally swiped my card, but when I press the button the first time, it seems like it just prints Track 1 two times. once I press the button for a 2nd time, it seem to type Track 2 two times.

Does this seem like the correct behaviour, or have I done something wrong here?

Looking forward to getting this working :+1:

samyk, 2018-12-03:
What did you define as track 1 and what as track 2?

jLynx, 2018-12-03:
Hi Samy
So what you are saying makes sense, now just confirming.
So 1 button press runs both tracks "at the same time". Which should work fine.
The 2nd button press is like a backup in case the PoS couldn't read track 2, so it plays it again?

Then after that 2nd button press, the code restarts and plays the first track again when pressed(3rd press), etc etc etc

Would this be correct?

samyk, 2018-12-03:
Correct.

roboyaar, 2022-12-28:
hi sir
would you please guide me that on what amount did you set the fuse bit during the programming?

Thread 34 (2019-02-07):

"Error reading card" on some terminals

jLynx, 2019-02-07:
Hi Samy & GitHub community

For the most part, I have it working. This seems to work on about 70% of the terminals I have used it on. I have been using it for about 3 weeks now non stop (poor bank account).
But at some terminals, it just wont work. It says, "Error Reading Card". Do you know what might be causing this problem?
I think could be one of these:

- Coil
- Code
- Motor Driver (DRV8833)
- Power output

I have tested with the original card it has cloned and the card works fine on the specific terminal.
Have you or anyone else run into this issue before and would you have any ideas on what the issue could be and how to fix it?

Looking forward working past this issue so I can leave my credit card in my wallet.

If anyone has any questions, I would be happy to answer.

I also have videos of it working and a video of it failing if that would help anyone.

jn234, 2020-10-23:
k

samyk, 2023-07-23:
Could be the terminal not supporting the reversed track, or maybe the terminal requires both tracks to be presented simultaneously, or maybe the combo of two tracks is the issue in of itself. Next time you run into one can you take a pic and get model info as much as you can for it so we can look at it directly?

jn234, 2023-07-23:
thank god your alive
On Sat, Jul 22, 2023 at 8:50 PM samy kamkar ***@***.***>
wrote:

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

jLynx, 2023-07-23:
> Could be the terminal not supporting the reversed track, or maybe the terminal requires both tracks to be presented simultaneously, or maybe the combo of two tracks is the issue in of itself. Next time you run into one can you take a pic and get model info as much as you can for it so we can look at it directly?

Hey Samy! Yep I will do when I have some time to pick up the project again

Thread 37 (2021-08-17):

Does it work on attiny13a?

AlexTheDuck, 2021-08-17:
I want to use MagSpoof on attiny13a and want to know if that is possible.

samyk, 2023-07-23:
You likely need to adjust the code but I don't see why this wouldn't work on other microcontrollers so long as you have the number of pins and switching speed required on the GPIO (which is very slow with the 200us between bit flips). Any sleep/ISR/register level stuff likely needs to be adjusted.

Closed 2023-07-23.

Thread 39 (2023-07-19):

how to read card wirelessly

flakka2022, 2023-07-19:
it is possible to read card wirelessly using magspoof its self ? how ?

jLynx, 2023-07-19:
No, you need to read up on how magnetic cards work.

flakka2022, 2023-07-21:
good tip . Magnetic stripe must be touched to be read.

Closed 2023-07-21.

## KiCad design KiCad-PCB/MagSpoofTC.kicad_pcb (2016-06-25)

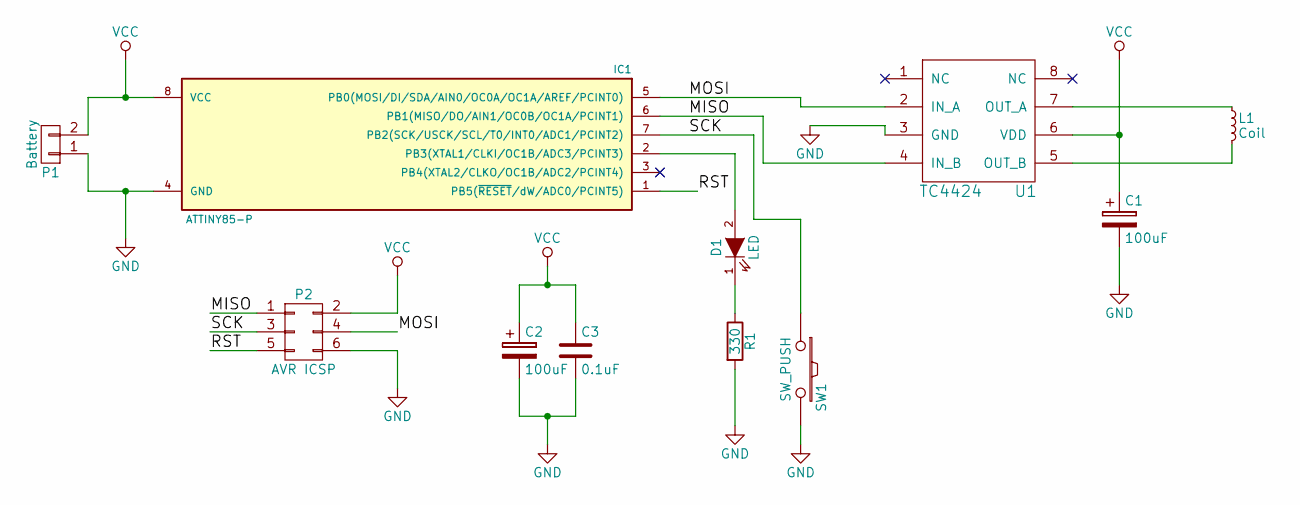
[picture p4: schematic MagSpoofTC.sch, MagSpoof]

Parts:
C1, C2: 100uF; 1411(3528m)-B%2CM%2CH%2CT-TANTALUM
C3: 0.1uF; C_0603_HandSoldering
D1: LED; LED-0805
IC1: ATTINY85-P; DIP-8_W7.62mm_LongPads
L1: Coil; Resistor_Horizontal_RM10mm
P1: Battery; Pin_Header_Straight_1x02
P2: AVR ICSP; Pin_Header_Straight_2x03
R1: 330; R_0603_HandSoldering
SW1: SW_PUSH; SW_PUSH_SMD
U1: TC4424; DIP-8_W7.62mm_LongPads

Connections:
/MISO: IC1.6 (PB1(MISO/DO/AIN1/OC0B/OC1A/PCINT1)), P2.1, U1.4 (IN_B)
/MOSI: IC1.5 (PB0(MOSI/DI/SDA/AIN0/OC0A/OC1A/AREF/PCI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), P2.4, U1.2 (IN_A)
/RST: IC1.1 (PB5(~RESET~/dW/ADC0/PCINT5)), P2.5
/SCK: IC1.7 (PB2(SCK/USCK/SCL/T0/INT0/ADC1/PCINT2)), P2.3, SW1.1
GND: C1.2, C2.2, C3.2, IC1.4 (GND), P1.1, P2.6, R1.2, SW1.2, U1.3 (GND)
unnamed: D1.1 (K), R1.1
unnamed: D1.2 (A), IC1.2 (PB3(XTAL1/CLKI/OC1B/ADC3/PCINT3))
unnamed: L1.1, U1.7 (OUT_A)
unnamed: L1.2, U1.5 (OUT_B)
VCC: C1.1, C2.1, C3.1, IC1.8 (VCC), P1.2, P2.2, U1.6 (VDD)

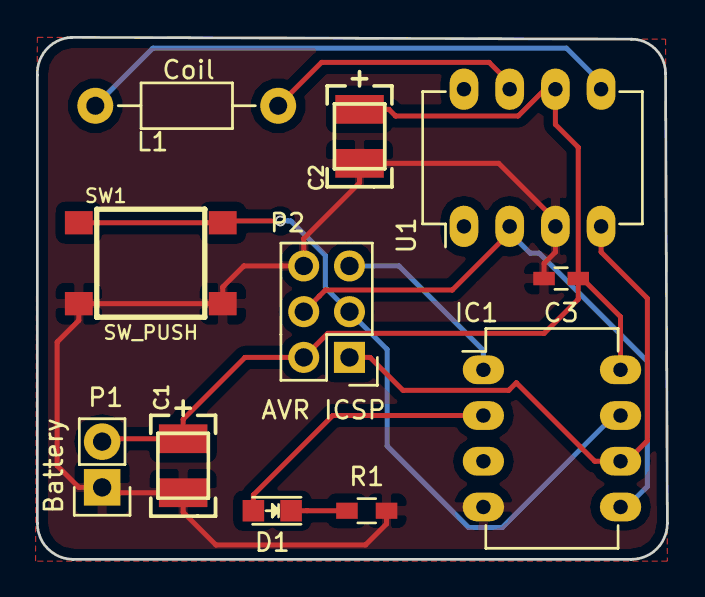
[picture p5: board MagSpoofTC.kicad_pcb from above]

Board: 2 copper layers, 35.0 x 29.0 mm, 11 parts (0 on the bottom side), 10 nets.

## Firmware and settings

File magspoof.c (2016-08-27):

/*
 * MagSpoof - "wireless" magnetic stripe/credit card emulator
*
 * by Samy Kamkar
 *
 * http://samy.pl/magspoof/
 *
 * - Allows you to store all of your credit cards and magstripes in one device
 * - Works on traditional magstripe readers wirelessly (no NFC/RFID required)
 * - Can disable Chip-and-PIN (code not included)
 * - Correctly predicts Amex credit card numbers + expirations from previous card number (code not included)
 * - Supports all three magnetic stripe tracks, and even supports Track 1+2 simultaneously
 * - Easy to build using Arduino or ATtiny
 *
 */

#include <avr/sleep.h>
#include <avr/interrupt.h>

#define PIN_A 0
#define PIN_B 1
#define ENABLE_PIN 3 // also green LED
#define SWAP_PIN 4 // unused
#define BUTTON_PIN 2
#define CLOCK_US 200

#define BETWEEN_ZERO 53 // 53 zeros between track1 & 2

#define TRACKS 2

// consts get stored in flash as we don't adjust them
const char* tracks[] = {
"%B123456781234567^LASTNAME/FIRST^YYMMSSSDDDDDDDDDDDDDDDDDDDDDDDDD?\0", // Track 1
";123456781234567=YYMMSSSDDDDDDDDDDDDDD?\0" // Track 2
};

char revTrack[41];

const int sublen[] = {
  32, 48, 48 };
const int bitlen[] = {
  7, 5, 5 };

unsigned int curTrack = 0;
int dir;

void setup()
{
  pinMode(PIN_A, OUTPUT);
  pinMode(PIN_B, OUTPUT);
  pinMode(ENABLE_PIN, OUTPUT);
  pinMode(BUTTON_PIN, INPUT_PULLUP);

  // blink to show we started up
  blink(ENABLE_PIN, 200, 3);

  // store reverse track 2 to play later
  storeRevTrack(2);
}

void blink(int pin, int msdelay, int times)
{
  for (int i = 0; i < times; i++)
  {
    digitalWrite(pin, HIGH);
    delay(msdelay);
    digitalWrite(pin, LOW);
    delay(msdelay);
  }
}

// send a single bit out
void playBit(int sendBit)
{
  dir ^= 1;
  digitalWrite(PIN_A, dir);
  digitalWrite(PIN_B, !dir);
  delayMicroseconds(CLOCK_US);

  if (sendBit)
  {
    dir ^= 1;
    digitalWrite(PIN_A, dir);
    digitalWrite(PIN_B, !dir);
  }
  delayMicroseconds(CLOCK_US);

}

// when reversing
void reverseTrack(int track)
{
  int i = 0;
  track--; // index 0
  dir = 0;

  while (revTrack[i++] != '\0');
  i--;
  while (i--)
    for (int j = bitlen[track]-1; j >= 0; j--)
      playBit((revTrack[i] >> j) & 1);
}

// plays out a full track, calculating CRCs and LRC
void playTrack(int track)
{
  int tmp, crc, lrc = 0;
  track--; // index 0
  dir = 0;

  // enable H-bridge and LED
  digitalWrite(ENABLE_PIN, HIGH);

  // First put out a bunch of leading zeros.
  for (int i = 0; i < 25; i++)
    playBit(0);

  //
  for (int i = 0; tracks[track][i] != '\0'; i++)
  {
    crc = 1;
    tmp = tracks[track][i] - sublen[track];

    for (int j = 0; j < bitlen[track]-1; j++)
    {
      crc ^= tmp & 1;
      lrc ^= (tmp & 1) << j;
      playBit(tmp & 1);
      tmp >>= 1;
    }
    playBit(crc);
  }

  // finish calculating and send last "byte" (LRC)
  tmp = lrc;
  crc = 1;
  for (int j = 0; j < bitlen[track]-1; j++)
  {
    crc ^= tmp & 1;
    playBit(tmp & 1);
    tmp >>= 1;
  }
  playBit(crc);

  // if track 1, play 2nd track in reverse (like swiping back?)
  if (track == 0)
  {
    // if track 1, also play track 2 in reverse
    // zeros in between
    for (int i = 0; i < BETWEEN_ZERO; i++)
      playBit(0);

    // send second track in reverse
    reverseTrack(2);
  }

  // finish with 0's
  for (int i = 0; i < 5 * 5; i++)
    playBit(0);

  digitalWrite(PIN_A, LOW);
  digitalWrite(PIN_B, LOW);
  digitalWrite(ENABLE_PIN, LOW);

}



// stores track for reverse usage later
void storeRevTrack(int track)
{
  int i, tmp, crc, lrc = 0;
  track--; // index 0
  dir = 0;

  for (i = 0; tracks[track][i] != '\0'; i++)
  {
    crc = 1;
    tmp = tracks[track][i] - sublen[track];

    for (int j = 0; j < bitlen[track]-1; j++)
    {
      crc ^= tmp & 1;
      lrc ^= (tmp & 1) << j;
      tmp & 1 ?
        (revTrack[i] |= 1 << j) :
        (revTrack[i] &= ~(1 << j));
      tmp >>= 1;
    }
    crc ?
      (revTrack[i] |= 1 << 4) :
      (revTrack[i] &= ~(1 << 4));
  }

  // finish calculating and send last "byte" (LRC)
  tmp = lrc;
  crc = 1;
  for (int j = 0; j < bitlen[track]-1; j++)
  {
    crc ^= tmp & 1;
    tmp & 1 ?
      (revTrack[i] |= 1 << j) :
      (revTrack[i] &= ~(1 << j));
    tmp >>= 1;
  }
  crc ?
    (revTrack[i] |= 1 << 4) :
    (revTrack[i] &= ~(1 << 4));

  i++;
  revTrack[i] = '\0';
}

void sleep()
{
  GIMSK |= _BV(PCIE);                     // Enable Pin Change Interrupts
  PCMSK |= _BV(PCINT2);                   // Use PB3 as interrupt pin
  ADCSRA &= ~_BV(ADEN);                   // ADC off
  set_sleep_mode(SLEEP_MODE_PWR_DOWN);    // replaces above statement

  MCUCR &= ~_BV(ISC01);
  MCUCR &= ~_BV(ISC00);       // Interrupt on rising edge
  sleep_enable();                         // Sets the Sleep Enable bit in the MCUCR Register (SE BIT)
  sei();                                  // Enable interrupts
  sleep_cpu();                            // sleep

  cli();                                  // Disable interrupts
  PCMSK &= ~_BV(PCINT2);                  // Turn off PB3 as interrupt pin
  sleep_disable();                        // Clear SE bit
  ADCSRA |= _BV(ADEN);                    // ADC on

  sei();                                  // Enable interrupts
}

// XXX move playtrack in here?
ISR(PCINT0_vect) {
  /*  noInterrupts();
   while (digitalRead(BUTTON_PIN) == LOW);

   delay(50);
   while (digitalRead(BUTTON_PIN) == LOW);
   playTrack(1 + (curTrack++ % 2));
   delay(400);

   interrupts();*/

}

void loop()
{

  //for(int i=0;i<10;i++){playTrack(1+(curTrack++%2));delay(3000);}

  sleep();

  noInterrupts();
  while (digitalRead(BUTTON_PIN) == LOW);

  delay(50);
  while (digitalRead(BUTTON_PIN) == LOW);
  playTrack(1 + (curTrack++ % 2));
  delay(400);

  interrupts();
  //playTrack(1 + (curTrack++ % 2));
}

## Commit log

2015-11-24 First release of MagSpoof, wireless magstripe/credit card spoofer/emulator
2015-11-24 added rest of the circuit
2015-11-25 Added Eagle schematic file
    [magspoof-schematic-dip.sch]
2015-11-25 Fix a couple of numeric units
2016-01-05 Fixed wrong pin connection, PB4->PB3 (thanks @shellster)
    [magspoof-schematic-dip.sch]
2016-01-08 Update README to use correct schematic rendering
    The image was updated in commit: https://github.com/samyk/magspoof/commit/f7f1d3c868b5509da58ddc3946a1869d8c942584
    but not updated in the README so it was difficult to find.
2016-01-20 Add Schematic and PCB in Kicad
    [MagSpoof.kicad_pcb, MagSpoof.sch]
2016-06-25 New version with TC4424
    [MagSpoof.kicad_pcb, MagSpoof.sch]
2016-06-25 New version with TC4424 Kicad
    [MagSpoofTC.kicad_pcb, MagSpoofTC.sch]
2016-06-25 Add BOM
    [BOM.csv]
2022-07-03 Update BOM.csv
    Add columns for both English and Spanish languages.
    [BOM.csv]

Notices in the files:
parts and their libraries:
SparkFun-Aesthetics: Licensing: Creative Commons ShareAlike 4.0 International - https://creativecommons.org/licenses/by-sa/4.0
